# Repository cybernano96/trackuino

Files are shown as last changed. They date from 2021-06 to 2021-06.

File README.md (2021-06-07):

Banner

This is a modified version of "Trackuino": an open-source APRS tracker based on the Arduino platform. It was designed primarily to track high altitude balloons, so it has other handy features like reading temperature sensors and a buzzer for acoustic location.

Trackuino is intended for use by licensed radio amateurs.

This modified version supports serial via SoftwareSerial and the DRA818V radio module

**Please note:** This project is a fork of Trackuino, they are the original creators of the code.

Features
========

 * Custom PCB
 * GPS: any NMEA GPS will work fine
 * Radio: DRA818V (500/1000 mW).
 * 1200 bauds AFSK using 8-bit PWM
 * Sends out standard APRS position messages (latitude, longitude, altitude, course, speed and time).
 * Internal/external temperature sensors (LM60) to read temperature in and outside the payload
 * Active/passive buzzer support to ease acoustic payload location.
 * 1 x SMA female plugs (radio out)
 * Open source (GPLv2 license), both software and hardware. In other words, do whatever you want with it: modify it, add it to your project, etc. as long as you opensource your modifications as well.

Status
========

 * GPS ok!
 * DRA818V ok!
 * APRS AF OUT ok!
 * Buzzer ok!
 * Temp Sensor ok!

Download
========

The latest version is 1.52.

Use the `Download ZIP` button to get the source code.

Building
========

If you are building for the Arduino platform you need Arduino IDE version 1.8.13 or higher. Get it from the [Arduino web site](http://arduino.cc/).

Unzip the firmware in your sketches directory and load it up by double-clicking on trackuino.ino.

The single most important configuration file is "config.h". The file is self-documented. Here is where you set up your callsign, among other things.

Flashing
========

**Important**: When flashing the Arduino/Uno32, remove the Venus GPS or the entire Trackuino shield. After flashing the firmware, you can plug it back in. The GPS and the host computer share the same serial port on the AVR, so they will conflict when used together.

Hardware
========

The [Mini APRS Tracker](https://www.iu2frl.it/micro-aprs-tracker/) contains all the informations. PCB drawings coming soon!

Related projects
================

Some other HAB-related projects I wrote:

  * https://www.iu2frl.it/tracker-aprs-su-icom-ic-e2820/ - APRS Tracker for ICOM IC-2820
  * https://www.iu2frl.it/arduino-aprs-beacon/ - an APRS beacon
  * https://www.iu2frl.it/category/autocostruzione/aprs-autocostruzione/ - APRS related articles

Support
=======

Discuss firmware bugs or suggestions in the issue tracker.

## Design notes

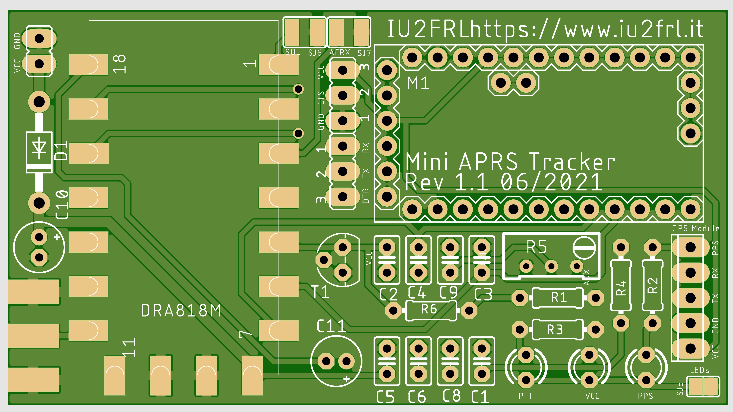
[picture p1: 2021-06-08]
Circuit/Top.PNG

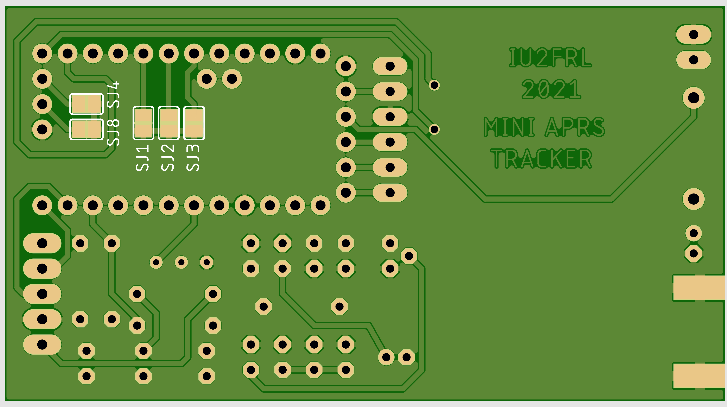
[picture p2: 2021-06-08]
Circuit/Bottom.PNG

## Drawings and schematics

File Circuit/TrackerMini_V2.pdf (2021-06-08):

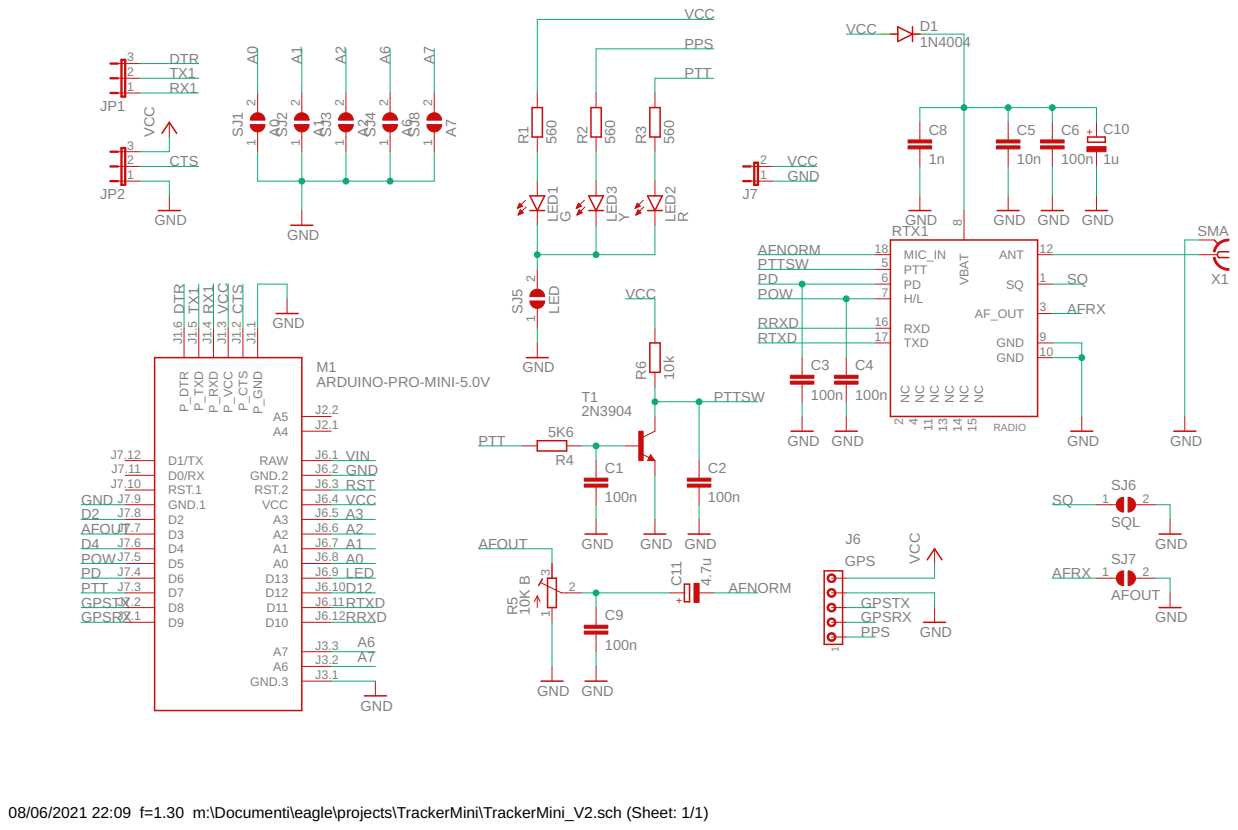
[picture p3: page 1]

08/06/2021 22:09 f=1.30 m:\Documenti\eagle\projects\TrackerMini\TrackerMini_V2.sch (Sheet: 1/1)

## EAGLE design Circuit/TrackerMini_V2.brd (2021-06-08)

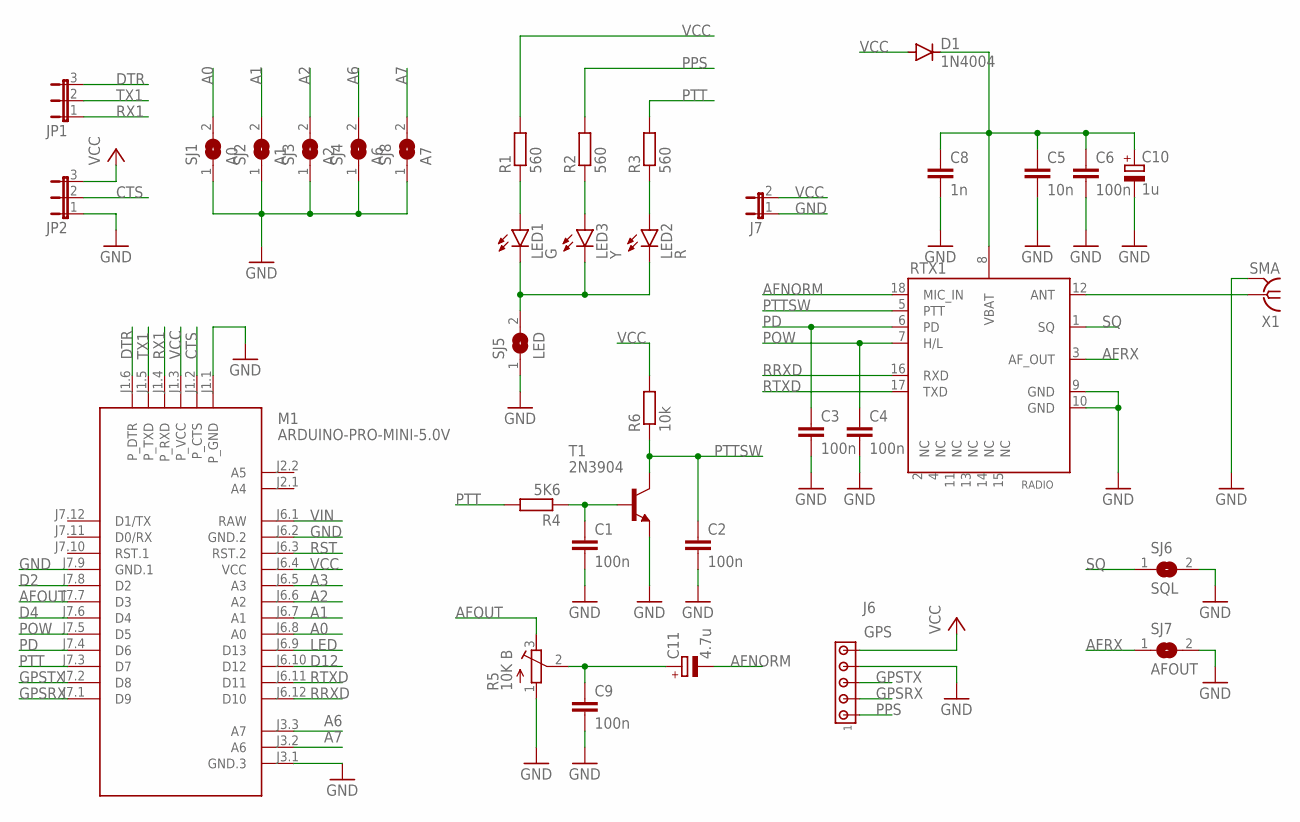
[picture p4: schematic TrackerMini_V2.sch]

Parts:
C1, C2, C3, C4, C6, C9: 100n; C025-025X050
C5: 10n; C025-025X050
C8: 1n; C025-025X050
C10: 1u; E2-5
C11: 4.7u; E2-5
D1: 1N4004; DO41-10
J6: GPS; 10X05MTA
J7: JP1E; JP1
JP1, JP2: JP2E; JP2
LED1: G; LED3MM
LED2: R; LED3MM
LED3: Y; LED3MM
M1: ARDUINO-PRO-MINI-5.0V; ARDUINO-PRO-MINI
R1, R2, R3: 560; 0204/7
R4: 5K6; 0204/7
R5: 10K B; RTRIM64W
R6: 10k; 0204/7
RTX1: RADIO; DRA818A
SJ1: A0; SJ
SJ2: A1; SJ
SJ3: A2; SJ
SJ4: A6; SJ
SJ5: LED; SJ
SJ6: SQL; SJW
SJ7: AFOUT; SJW
SJ8: A7; SJ
T1: 2N3904; TO92
X1: SMA; J502-ND-142-0701-801/806

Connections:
A0: M1.J6.8 (A0), SJ1.2
A1: M1.J6.7 (A1), SJ2.2
A2: M1.J6.6 (A2), SJ3.2
A3: M1.J6.5 (A3)
A6: M1.J3.3 (A7), SJ4.2
A7: M1.J3.2 (A6), SJ8.2
AFNORM: C11.-, RTX1.18 (MIC_IN)
AFOUT: M1.J7.7 (D3), R5.3 (E)
AFRX: RTX1.3 (AF_OUT), SJ7.1
CTS: JP2.2, M1.J1.2 (P_CTS)
D2: M1.J7.8 (D2)
D4: M1.J7.6 (D4)
D12: M1.J6.10 (D12)
DTR: JP1.3, M1.J1.6 (P_DTR)
GND: C1.2, C2.2, C3.2, C4.2, C5.2, C6.2, C8.2, C9.2, C10.-, J6.4, J7.1, JP2.1, M1.J1.1 (P_GND), M1.J3.1 (GND.3), M1.J6.2 (GND.2), M1.J7.9 (GND.1), R5.1 (A), RTX1.9 (GND), RTX1.10 (GND), SJ1.1, SJ2.1, SJ3.1, SJ4.1, SJ5.1, SJ6.2, SJ7.2, SJ8.1, T1.3 (E), X1.G@1 (2), X1.G@2 (2), X1.G@3 (2), X1.G@4 (2)
GPSRX: J6.2, M1.J7.1 (D9)
GPSTX: J6.3, M1.J7.2 (D8)
LED: M1.J6.9 (D13)
unnamed: LED1.A, R1.1
unnamed: LED3.A, R2.1
unnamed: LED2.A, R3.1
unnamed: LED1.K (C), LED2.K (C), LED3.K (C), SJ5.2
unnamed: RTX1.12 (ANT), X1.1
unnamed: C1.1, R4.1, T1.2 (B)
unnamed: C9.1, C11.+, R5.2 (S)
unnamed: C5.1, C6.1, C8.1, C10.+, D1.C, RTX1.8 (VBAT)
PD: C3.1, M1.J7.4 (D6), RTX1.6 (PD)
POW: C4.1, M1.J7.5 (D5), RTX1.7 (H/L)
PPS: J6.1, R2.2
PTT: M1.J7.3 (D7), R3.2, R4.2
PTTSW: C2.1, R6.1, RTX1.5 (PTT), T1.1 (C)
RRXD: M1.J6.12 (D10), RTX1.16 (RXD)
RST: M1.J6.3 (RST.2)
RTXD: M1.J6.11 (D11), RTX1.17 (TXD)
RX1: JP1.1, M1.J1.4 (P_RXD)
SQ: RTX1.1 (SQ), SJ6.1
TX1: JP1.2, M1.J1.5 (P_TXD)
VCC: D1.A, J6.5, J7.2, JP2.3, M1.J1.3 (P_VCC), M1.J6.4 (VCC), R1.2, R6.2
VIN: M1.J6.1 (RAW)

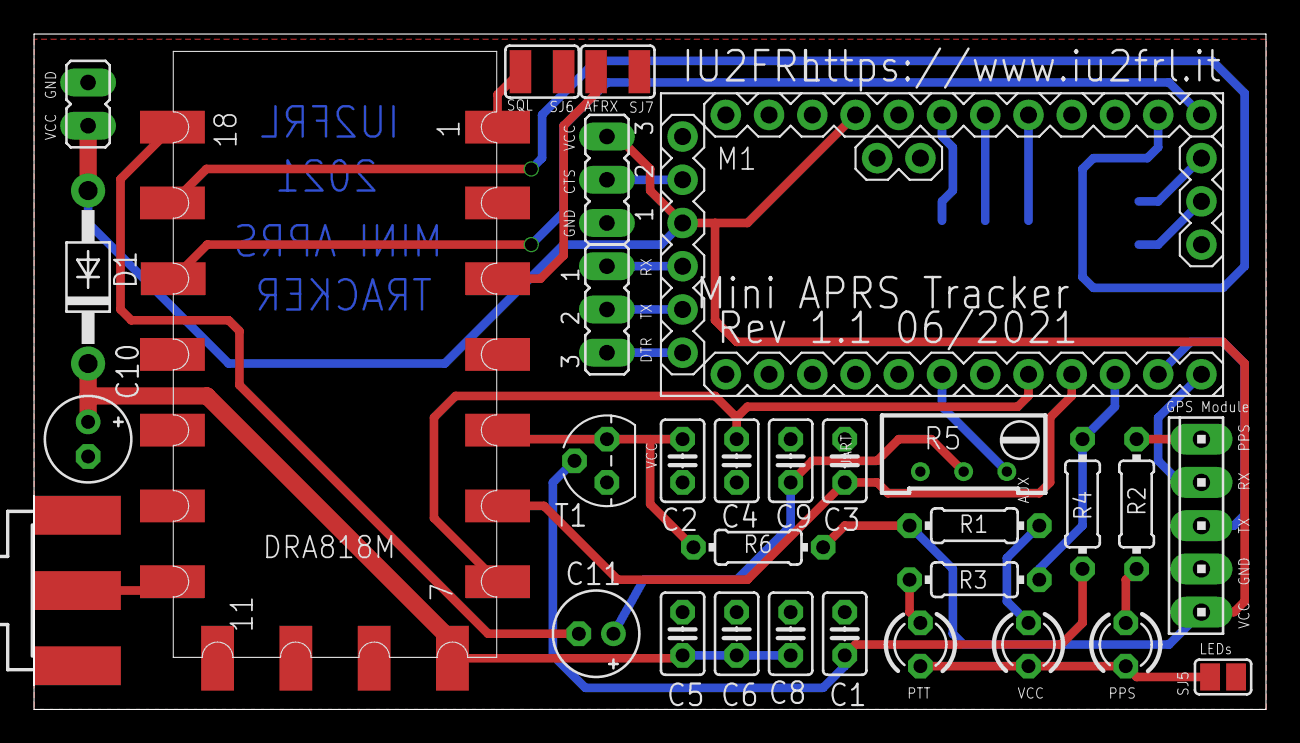
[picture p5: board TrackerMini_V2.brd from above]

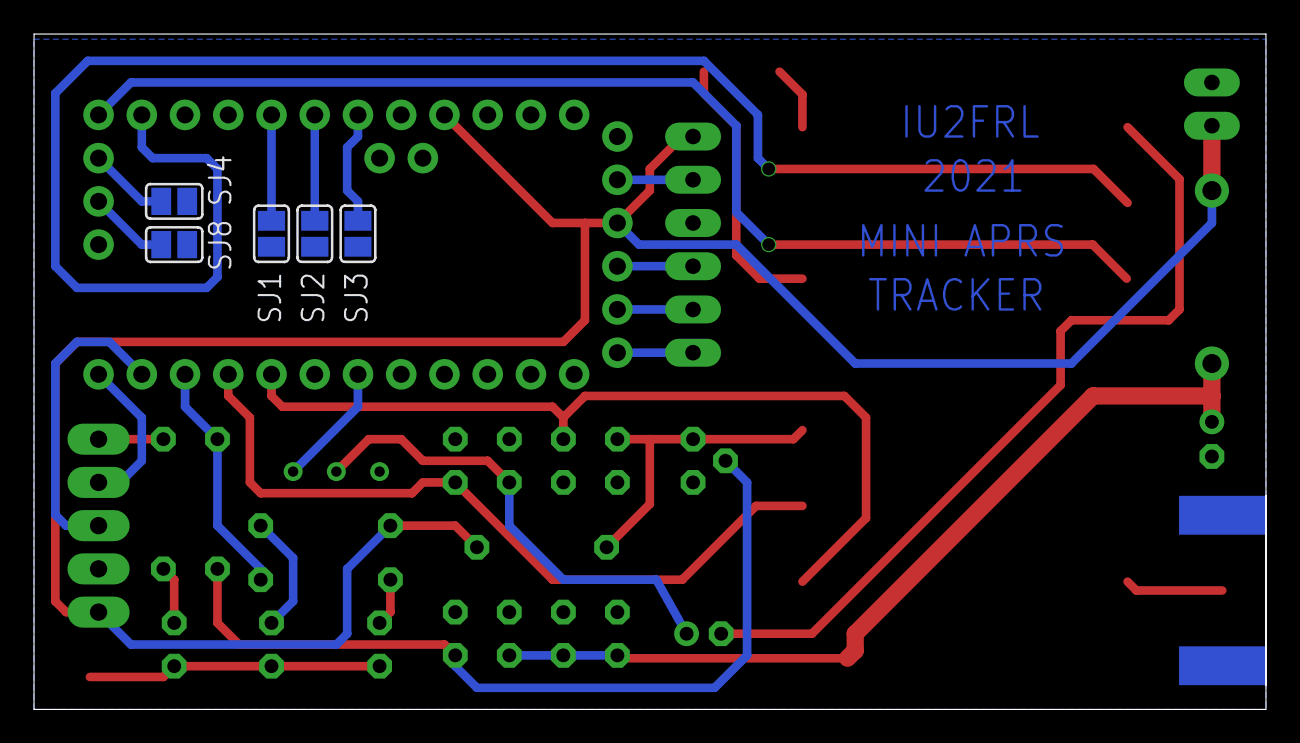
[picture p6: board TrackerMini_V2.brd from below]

Board: 2 copper layers, 72.4 x 39.7 mm, 36 parts (5 on the bottom side), 32 nets.

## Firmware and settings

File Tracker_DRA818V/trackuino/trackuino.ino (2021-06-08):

/* trackuino copyright (C) 2010  EA5HAV Javi
 *
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
 * You should have received a copy of the GNU General Public License
 * along with this program; if not, write to the Free Software
 * Foundation, Inc., 51 Franklin Street, Fifth Floor, Boston, MA  02110-1301, USA.
 */

// Mpide 22 fails to compile Arduino code because it stupidly defines ARDUINO 
// as an empty macro (hence the +0 hack). UNO32 builds are fine. Just use the
// real Arduino IDE for Arduino builds. Optionally complain to the Mpide
// authors to fix the broken macro.
#if (ARDUINO + 0) == 0
#error "Oops! We need the real Arduino IDE (version 22 or 23) for Arduino builds."
#error "See trackuino.pde for details on this"

// Refuse to compile on arduino version 21 or lower. 22 includes an 
// optimization of the USART code that is critical for real-time operation
// of the AVR code.
#elif (ARDUINO + 0) < 180
#error "Oops! We need Arduino 1.8 or higher"
#error "See trackuino.pde for details on this"

#endif


// Trackuino custom libs
#include "config.h"
#include "afsk_avr.h"
#include "afsk_pic32.h"
#include "aprs.h"
#include "buzzer.h"
#include "gps.h"
#include "pin.h"
#include "power.h"
#include "sensors_avr.h"
#include "sensors_pic32.h"
#include "dra818.h"

#include <Arduino.h>

// Module constants
static const uint32_t VALID_POS_TIMEOUT = 2000;  // ms

// Module variables
static int32_t next_aprs = 0;

// Current FIX ok
//bool nowfix = false;
// At least one FIX
//bool onefix = true;

SoftwareSerial gpsSerial(GPS_RX, GPS_TX);
SoftwareSerial fakeSerial(EMPTYA, EMPTYB);

void setup()
{
  // Start Serial
  Serial.begin(230400);
  
  //LED Pin
  pinMode(LED_PIN, OUTPUT);
  pin_write(LED_PIN, LOW);
  
  // Due to a problem on V1.00 PCB we cannot use D12
  //pinMode(12, INPUT);

#ifdef DEBUG_RESET
  Serial.println("RESET");
#endif

  // init all components
  buzzer_setup();
  afsk_setup();
  gps_setup();
  sensors_setup();
  dorji_sequence();

  fakeSerial.begin(GPS_BAUDRATE);
  gpsSerial.begin(GPS_BAUDRATE);
  
  #ifdef DEBUG_GPS
      Serial.println("GPS Started");
  #endif
  
#ifdef DEBUG_SENS
  Serial.print("Ti=");
  Serial.print(sensors_int_lm60());
  Serial.print(", Te=");
  Serial.print(sensors_ext_lm60());
  Serial.print(", Vin=");
  Serial.println(sensors_vin());
#endif

#ifdef DEBUG_PROT
    // Transmit empty data just to check AF OUT
    next_aprs = millis() + 3000;
#else
  // Do not start until we get a valid time reference
  // for slotted transmissions.
  if (APRS_SLOT >= 0) {
    do {
      while (! gpsSerial.available())
        power_save();
    } while (! gps_decode(gpsSerial.read()));
    
    next_aprs = millis() + 1000 *
      (APRS_PERIOD - (gps_seconds + APRS_PERIOD - APRS_SLOT) % APRS_PERIOD);
  }
  else {
    next_aprs = millis();
  }  
#endif
  // TODO: beep while we get a fix, maybe indicating the number of
  // visible satellites by a series of short beeps?
}

void get_pos()
{ 
  gpsSerial.listen();
  
  // Get a valid position from the GPS
  int valid_pos = 0;
  uint32_t timeout = millis();

#ifdef DEBUG_GPS
  Serial.println("\nget_pos()");
#endif

  gps_reset_parser();

  do {
    if (Serial.available())
      valid_pos = gps_decode(gpsSerial.read());
  } while ( (millis() - timeout < VALID_POS_TIMEOUT) && ! valid_pos) ;

  if (valid_pos) {
    if (gps_altitude > BUZZER_ALTITUDE) {
      buzzer_off();   // In space, no one can hear you buzz
    } else {
      buzzer_on();
    }
  }
}

void loop()
{
  // Time for another APRS frame
  if ((int32_t) (millis() - next_aprs) >= 0) {
    get_pos();
    fakeSerial.listen();
    delay(500);
    aprs_send();
    
    #ifdef DEBUG_PROT
    next_aprs += 3000;
    #else
    next_aprs += APRS_PERIOD * 1000L;
    #endif
    while (afsk_flush()) {
      power_save();
    }

#ifdef DEBUG_MODEM
    // Show modem ISR stats from the previous transmission
    afsk_debug();
#endif

  } else {
    #ifdef DEBUG_GPS
      Serial.println("GPS Receive");
    #endif
    
    gpsSerial.listen();
    
    // Discard GPS data received during sleep window
    while (gpsSerial.available()) {
      gpsSerial.read();
    }
  }

  power_save(); // Incoming GPS data or interrupts will wake us up
}

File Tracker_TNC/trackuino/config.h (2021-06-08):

/* trackuino copyright (C) 2010  EA5HAV Javi
 *
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
 * You should have received a copy of the GNU General Public License
 * along with this program; if not, write to the Free Software
 * Foundation, Inc., 51 Franklin Street, Fifth Floor, Boston, MA  02110-1301, USA.
 */

#ifndef __CONFIG_H__
#define __CONFIG_H__


// --------------------------------------------------------------------------
// THIS IS THE TRACKUINO FIRMWARE CONFIGURATION FILE. YOUR CALLSIGN AND
// OTHER SETTINGS GO HERE.
//
// NOTE: all pins are Arduino based, not the Atmega chip. Mapping:
// http://www.arduino.cc/en/Hacking/PinMapping
// --------------------------------------------------------------------------


// --------------------------------------------------------------------------
// APRS config (aprs.c)
// --------------------------------------------------------------------------

// Set your callsign and SSID here. Common values for the SSID are
// (from http://zlhams.wikidot.com/aprs-ssidguide):
//
// - Balloons:  11
// - Cars:       9
// - Home:       0
// - IGate:      5
#define S_CALLSIGN      "IU2FRL"
#define S_CALLSIGN_ID   10

// Destination callsign: APRS (with SSID=0) is usually okay.
#define D_CALLSIGN      "APRS"
#define D_CALLSIGN_ID   0

// Digipeating paths:
// (read more about digipeating paths here: http://wa8lmf.net/DigiPaths/ )
// The recommended digi path for a balloon is WIDE2-1 or pathless. The default
// is pathless. Uncomment the following two lines for WIDE2-1 path:
#define DIGI_PATH1      "WIDE2"
#define DIGI_PATH1_TTL  1

// APRS comment: this goes in the comment portion of the APRS message. You
// might want to keep this short. The longer the packet, the more vulnerable
// it is to noise. 
#define APRS_COMMENT    "Mini APRS Tracker by IU2FRL riding my HD Iron 883"
#define APRS_SYMBOL '<' // '<': Motorcycle '>': Car

// Not implemented yet!
#define APRS_COMMENT_NOFIX    "Mini APRS Tracker by IU2FRL - Waiting for GPS FIX"
#define START_LAT "4510.34N"  // GPS Coordinates when no fix yet (APRS Format!)
#define START_LON "01047.13E"

// --------------------------------------------------------------------------
// AX.25 config (ax25.cpp)
// --------------------------------------------------------------------------

// TX delay in milliseconds
#define TX_DELAY      300

// --------------------------------------------------------------------------
// Tracker config (trackuino.pde)
// --------------------------------------------------------------------------

// APRS packets are slotted so that multiple trackers can be used without
// them stepping on one another. The transmission times are governed by
// the formula:
//
//         APRS_SLOT (seconds) + n * APRS_PERIOD (seconds)
//
// When launching multiple balloons, use the same APRS_PERIOD in all balloons
// and set APRS_SLOT so that the packets are spaced equally in time.
// Eg. for two balloons and APRS_PERIOD = 60, set APRS_SLOT to 0 and 30, 
// respectively. The first balloon will transmit at 00:00:00, 00:01:00, 
// 00:02:00, etc. and the second balloon will transmit at 00:00:30, 00:01:30,
// 00:02:30, etc.
#define APRS_SLOT     0     // seconds. -1 disables slotted transmissions
#define APRS_PERIOD   60    // seconds

// GPS baud rate (in bits per second).
#define GPS_BAUDRATE  9600
#define GPS_RX        8
#define GPS_TX        9

// --------------------------------------------------------------------------
// Modem config (afsk.cpp)
// --------------------------------------------------------------------------

// AUDIO_PIN is the audio-out pin. The audio is generated by timer 2 using
// PWM, so the only two options are pins 3 and 11.
// Pin 11 doubles as MOSI, so I suggest using pin 3 for PWM and leave 11 free
// in case you ever want to interface with an SPI device.
#define AUDIO_PIN       3

// Pre-emphasize the 2200 tone by 6 dB. This is actually done by 
// de-emphasizing the 1200 tone by 6 dB and it might greatly improve
// reception at the expense of poorer FM deviation, which translates
// into an overall lower amplitude of the received signal. 1 = yes, 0 = no.
#define PRE_EMPHASIS    1

// --------------------------------------------------------------------------
// Radio config (radio_hx1.cpp)
// --------------------------------------------------------------------------

// This is the PTT pin
#define PTT_PIN           7
#define POW_PIN           5
#define RTXD              10
#define RRXD              11
#define RPD               6
#define RBAUD             9600
#define TXFREQ            144.800
#define RXFREQ            144.800

// TX power 1: HIGH 0: LOW
#define POUT 0

// --------------------------------------------------------------------------
// Sensors config (sensors.cpp)
// --------------------------------------------------------------------------
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

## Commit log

2021-06-07 GPS no-fix comment first write
    [config.h, trackuino.ino]
2021-06-08 Corretto interferenza con SoftwareSerial
    [config.h, trackuino.ino]
2021-06-08 Configured sensors to be optional
2021-06-08 Aggiunti PCB
    [TrackerMini_V2.brd, TrackerMini_V2.sch]

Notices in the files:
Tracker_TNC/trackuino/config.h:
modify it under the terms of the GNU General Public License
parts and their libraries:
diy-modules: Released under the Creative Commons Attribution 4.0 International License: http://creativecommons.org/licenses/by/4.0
